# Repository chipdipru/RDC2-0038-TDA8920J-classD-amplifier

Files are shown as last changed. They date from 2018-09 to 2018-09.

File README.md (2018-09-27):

<p><a href="https://static.chipdip.ru/lib/911/DOC003911405.jpg" class="galery">RDC2-0038</a></p>

<p>Модуль RDC2-0038 представляет собой высокопроизводительный усилитель мощности класса D. Усилитель построен на микросхеме TDA8920BJ. Это стереофонический аналоговый чип с цифровым усилителем, предназначенный для работы с 4-омными громкоговорителями мощностью до 110 Вт на канал.<br>RDC2-0038 сконфигурирован для работы с двумя каналами включенными по мостовой схеме (BTL).<br>На аналоговый вход усилителя можно подавать как несимметричный так и симметричный (дифференциальный) сигнал.<br>
 Встроенная система защиты отслеживает: перегрев, перегрузку и короткое замыкание выходов. При наличии одной из вышеперечисленных ошибок усилитель отключается, а после устранения ошибки восстанавливает работу.<br>Для обеспечения высококачественного высокоэффективного усиления звука требуется простой пассивный фильтр демодуляции цифрового сигнала. Модуль LCF.</p>
<h2>Технические характеристики</h2>
<p>Напряжение питания выходного каскада: ±12.5 ... ±30 В<br>Количество каналов: 2 x BTL<br>Сопротивление нагрузки: 3-8 Ом<br>Выходная мощность: BTL 110 Вт / 3 Ом 10% THD<br>Выходная мощность BTL 86 Вт / 4 Ом / 10% THD<br>Выходная мощность: PBTL 210 Вт / 6 Ом 10% THD<br>Выходная мощность: BTL 69 Вт / 4 Ом / 0,5% THD<br>Коэффициент нелинейных искажений:0.02%</p>
<p>Схема усилителя с выходными фильтрами.</p>
<p><a href="https://static.chipdip.ru/kits/9000493151/RDC2-0038_sch_full.png" class="galery">Схема</a></p>
<p>Блок-схема усилителя с выходными фильтрами.</p>
<p><a href="https://static.chipdip.ru/kits/9000493151/RDC2-0038-blockSSS.png" class="galery">Блок-Схема</a></p>
<p>Подробную инструкцию по включению и конфигурации усилителя можно найти в разделе «Документы».</p>
<p>Это открытый проект! Лицензия, под которой он распространяется – <a href="https://creativecommons.org/licenses/by-sa/3.0/" class="link">Creative Commons - Attribution - Share Alike license</a>.</p>

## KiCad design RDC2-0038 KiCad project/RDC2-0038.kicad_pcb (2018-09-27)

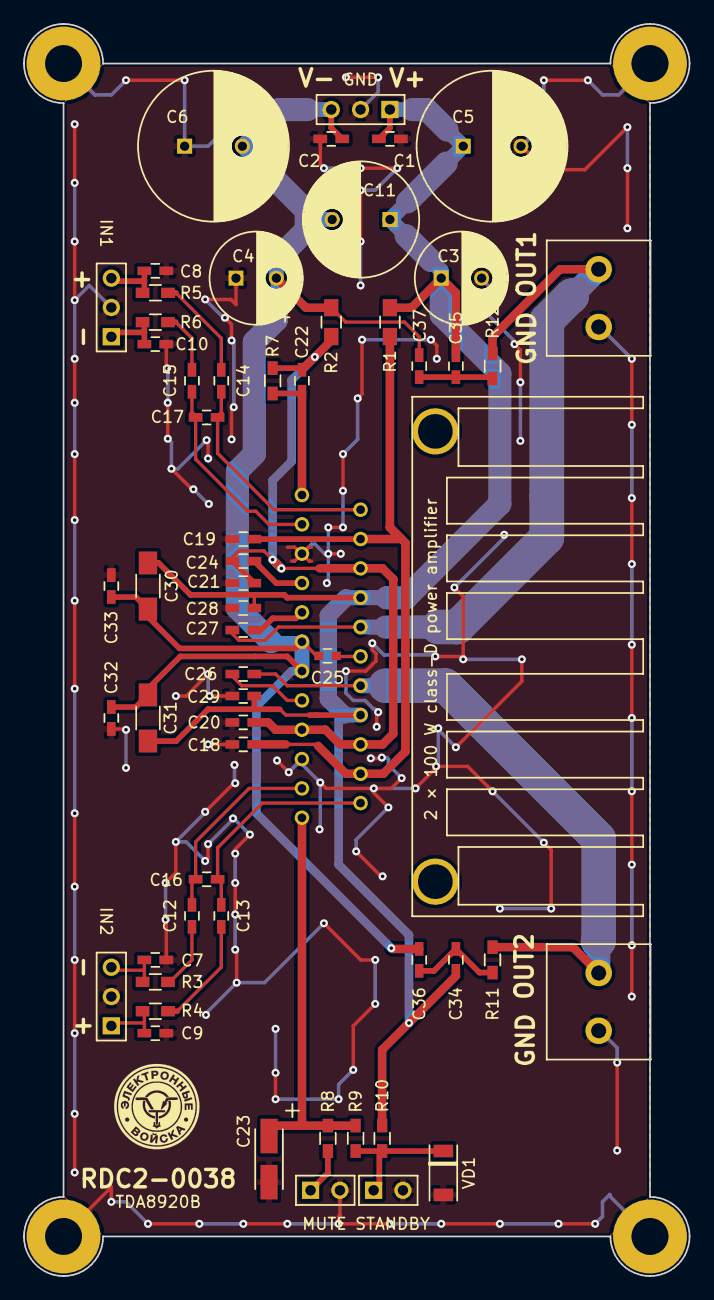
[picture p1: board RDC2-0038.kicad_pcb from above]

Board: 2 copper layers, 57.7 x 108.5 mm, 58 parts (0 on the bottom side), 29 nets.

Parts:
C1, C2, C7, C8, C9, C10, C12, C13, C14, C15, C16, C17, C18, C19, C20, C21, C22, C24, C26, C27, C28, C29, C32, C33, C34, C35, C36, C37: C; C_0603_HandSoldering
C3, C4: CP; C_Radial_D8_L11.5_P3.5
C5, C6: CP; C_Radial_D13_L21_P5
C11: CP; C_Radial_D10_L20_P5
C23: CP; TantalC_SizeA_EIA-3216_HandSoldering_mm
C25: C; C_0603
C30, C31: C; C_1206_HandSoldering
DA1: TDA8920BJ; SOT411-1
R1, R2: R; C_0805_HandSoldering
R3, R4, R5, R6, R7, R8, R9, R10, R11, R12: R; R_0603_HandSoldering
VD1: ZENER; Diode_SOD-80
XP1, XP2, XP3: CONN_01X03; Pin_Header_Straight_1x03_mm
XP4, XP5: CONN_01X02; Pin_Header_Straight_1x02_mm
XS1, XS2: CONN_01X02; Clem_2Pos_P5

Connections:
GND: C1.2, C2.1, C3.2, C4.1, C5.2, C6.1, C7.2, C8.2, C9.2, C10.2, C18.2, C19.2, C20.2, C21.2, C23.2, C28.2, C29.2, C32.2, C33.2, DA1.5, DA1.19, VD1.2, XP1.2, XP2.2, XP3.2, XP4.2, XP5.2, XS1.2, XS2.2
unnamed: C7.1, R3.2, XP2.3
unnamed: C8.1, R5.2, XP3.3
unnamed: C9.1, R4.2, XP2.1
unnamed: C10.1, R6.2, XP3.1
unnamed: C12.1, C16.1, DA1.21
unnamed: C12.2, R3.1
unnamed: C13.1, C16.2, DA1.22
unnamed: C13.2, R4.1
unnamed: C14.1, C17.1, DA1.2
unnamed: C14.2, R5.1
unnamed: C15.1, C17.2, DA1.3
unnamed: C15.2, R6.1
unnamed: C22.1, DA1.1, R7.1
unnamed: C23.1, DA1.23, R8.2, R9.2
unnamed: C24.1, DA1.7
unnamed: C25.1, DA1.12
unnamed: C26.1, DA1.15
unnamed: C26.2, DA1.14, R11.1, XS1.1
unnamed: C27.1, DA1.10, R12.1, XS2.1
unnamed: C27.2, DA1.9
unnamed: C34.1, C36.1, R11.2
unnamed: C35.1, C37.1, R12.2
unnamed: R8.1, XP4.1
unnamed: R9.1, R10.1, VD1.1, XP5.1
VA+: C18.1, C19.1, DA1.4, DA1.20, R1.2
VA-: C20.1, C21.1, C22.2, C24.2, DA1.6, DA1.17, DA1.18, R2.2, R7.2
VP+: C1.1, C3.1, C5.1, C11.1, C28.1, C29.1, C30.1, C31.1, C34.2, C35.2, DA1.8, DA1.16, R1.1, R10.2, XP1.1
VP-: C2.2, C4.2, C6.2, C11.2, C25.2, C30.2, C31.2, C32.1, C33.1, C36.2, C37.2, DA1.11, DA1.13, R2.1, XP1.3

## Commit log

2018-09-27 Gerber files
    [RDC2-0038-B.Cu.gbr, RDC2-0038-B.Mask.gbr, RDC2-0038-B.SilkS.gbr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]
2018-09-27 KiCad project
    [RDC2-0038-2018-09-27-16-03-24.sch, RDC2-0038.kicad_pcb, RDC2-0038.sch]
